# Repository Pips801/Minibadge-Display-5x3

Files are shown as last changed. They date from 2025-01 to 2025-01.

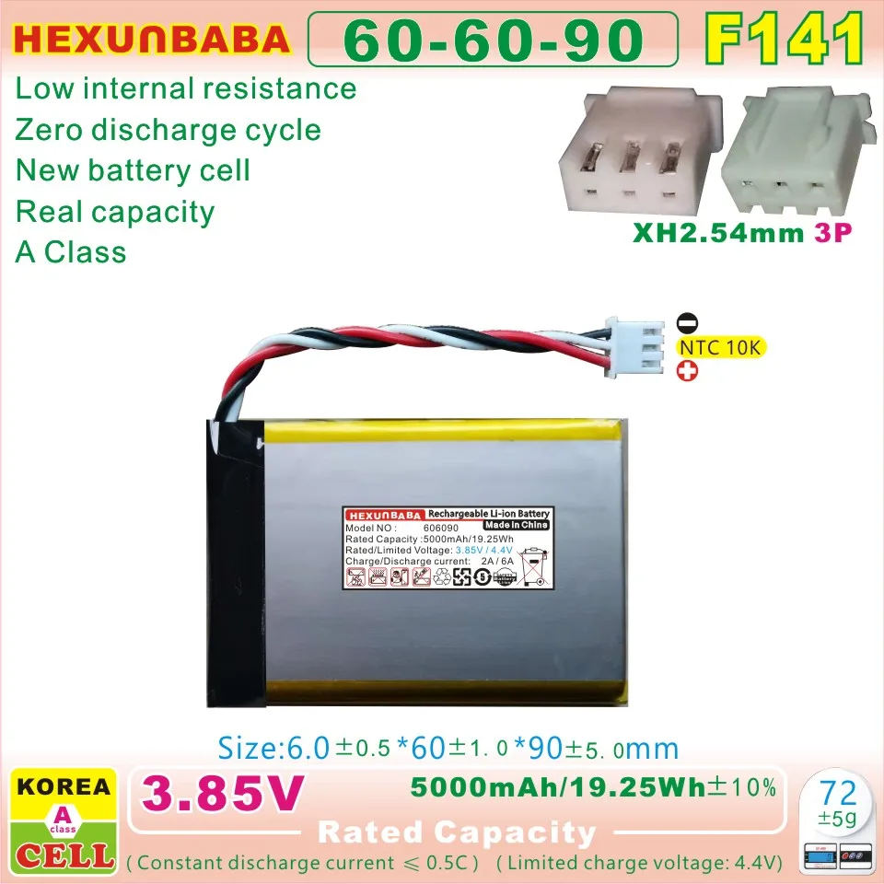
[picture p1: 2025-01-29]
Hardware/Main board/606090 F141 JST Battery.png

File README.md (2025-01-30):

# Minibadge-Display-5x3
 Battery-powered 5x3 SAINTCON Minibadge display

## Description
Battery-powered RP2040 controlled 5x3 minibadge display

MCU: RP2040

Battery: 606090 5000mAh + JST XH 3 pin 2.54mm

BMS: BQ25895

LEDs: WS2812B-2020

## Costs

| Completed? | Purchase type | Price | Cost per item |
| --- | --- | --- | --- |
| No | Parts | $161.01 | $3.22 |
| No | Main PCB | $69.00  | $1.38 |
| No | PCBA | $101.84 | $2.04 |
| No | Batteries | $215.00 | $4.30 |
| No | Front PCB | $50.01  | $1.00 |
| No | PCB Shipping | $150.00 | $3.00 |
| No | Battery Shipping | $100.00 | $2.00 |
| **Item quantity** | | **Total** | **Total cost per item** |
| 50 | | $846.86 | $16.94 |

| Completed? | Purchase type | Price | Cost per item |
| --- | --- | --- | --- |
| No | Parts | $131.22 | $5.25 |
| No | Main PCB | $28.70  | $1.15 |
| No | PCBA | $57.11  | $2.28 |
| No | Batteries | $107.50 | $4.30 |
| No | Front PCB | $37.50  | $1.50 |
| No | PCB Shipping | $80.00  | $3.20 |
| No | Battery Shipping | $53.35  | $2.13 |
| **Item quantity** | | **Total** | **Total cost per item** |
| 25 | | $495.38 | $19.82 |

## BOM

|Designator |Footprint |Quantity|Value |LCSC Part #|
|---|---|---|---|---|
|C1, C12, C13, C14, C15, C16, C17, C18, C19 |0603 |9 |4.7μF | |
|C10, C11, C20, C21, C22, C23, C24, C25, C26, C27, C28, C29, C34, C35, C36, C37, C38, C39, C40, C41|0402 |20 |0.1μF | |
|C2, C3, C6, C7, C9 |0603 |5 |10μF | |
|C31 |0402 |1 |1µF | |
|C32, C33 |0402 |2 |15pF | |
|C4 |1206 |1 |40μF |C426659 |
|C5 |0402 |1 |47nF | |
|C8 |0402 |1 |1µF |C52923 |
|D1 |D_SMB |1 |20v 5A |C14651 |
|D2, D3, D4, D5, D6, D7, D8, D9 |LED_WS2812B-2020_PLCC4_2.0x2.0mm |8 |WS2812B-2020 |C5349955 |
|J1 |PinSocket_2x05_P2.54mm_Vertical_SMD |1 |Board to Board | |
|J2 |JST_XH_S3B-XH-SM4-TB_1x03-1MP_P2.50mm_Horizontal |1 |BATT JST |C161860 |
|L1 |L_Vishay_IHLP-2525 |1 |2.2µH |C540967 |
|P1 |USB_C_Receptacle_HRO_TYPE-C-31-M-12 |1 |USB_C_Plug_USB2.0|C165948 |
|R1 |0603 |1 |5.23kΩ | |
|R10, R9 |0402 |2 |27.4Ω | |
|R11, R12, R13, R14, R15, R16 |0603 |6 |10kΩ | |
|R2 |0603 |1 |260Ω |C861779 |
|R3 |0603 |1 |30.1kΩ | |
|R4, R5 |0603 |2 |5.1k | |
|R6, R7, R8 |0603 |3 |1kΩ | |
|SW1 |SW_Push_1P1T_XKB_TS-1187A |1 |USB BOOT |C318884 |
|U1 |Texas_RTW_WQFN-24-1EP_4x4mm_P0.5mm_EP2.7x2.7mm_ThermalVias|1 |BQ25895 |C80200 |
|U10 |Crystal_SMD_Abracon_ABM8G-4Pin_3.2x2.5mm |1 |ABM8-272-T3 |C20625731  |
|U2 |SOIC-8_5.23x5.23mm_P1.27mm |1 |W25Q32JVSS |C82344 |
|U3 |QFN-10-RSE |1 |TS3USB221A |C128396 |
|U4, U5, U6, U7 |SOT-223-3_TabPin2 |4 |AP7361C-33E |C500795 |
|U8 |SOIC-8_3.9x4.9mm_P1.27mm |1 |TPM8837C |C7436831 |
|U9 |QFN-56-1EP_7x7mm_P0.4mm_EP3.2x3.2mm_ThermalVias |1 |RP2040 |C2040 |

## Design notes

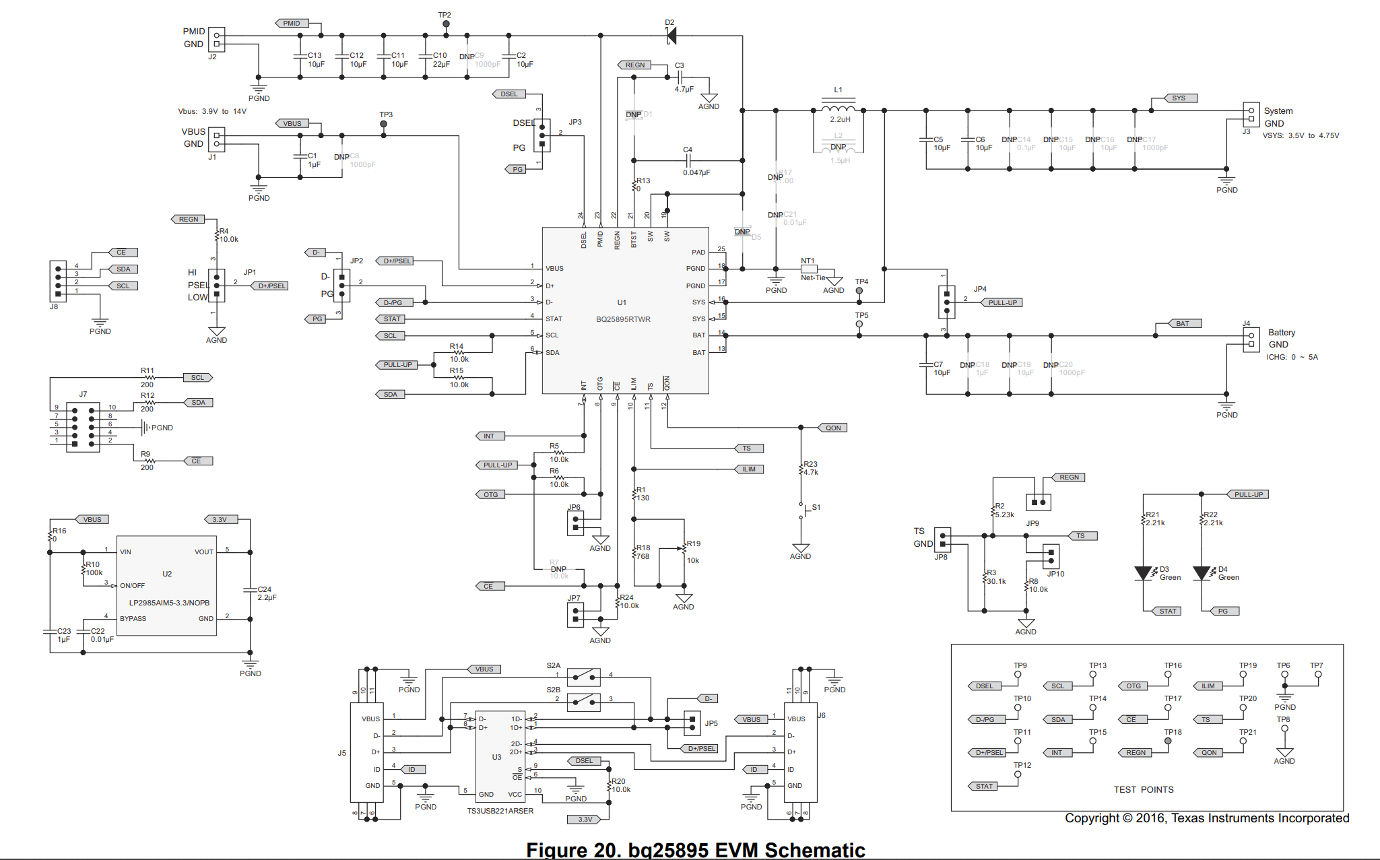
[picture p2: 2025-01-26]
Hardware/Main board/BQ25895RTW/EMV schematic.png

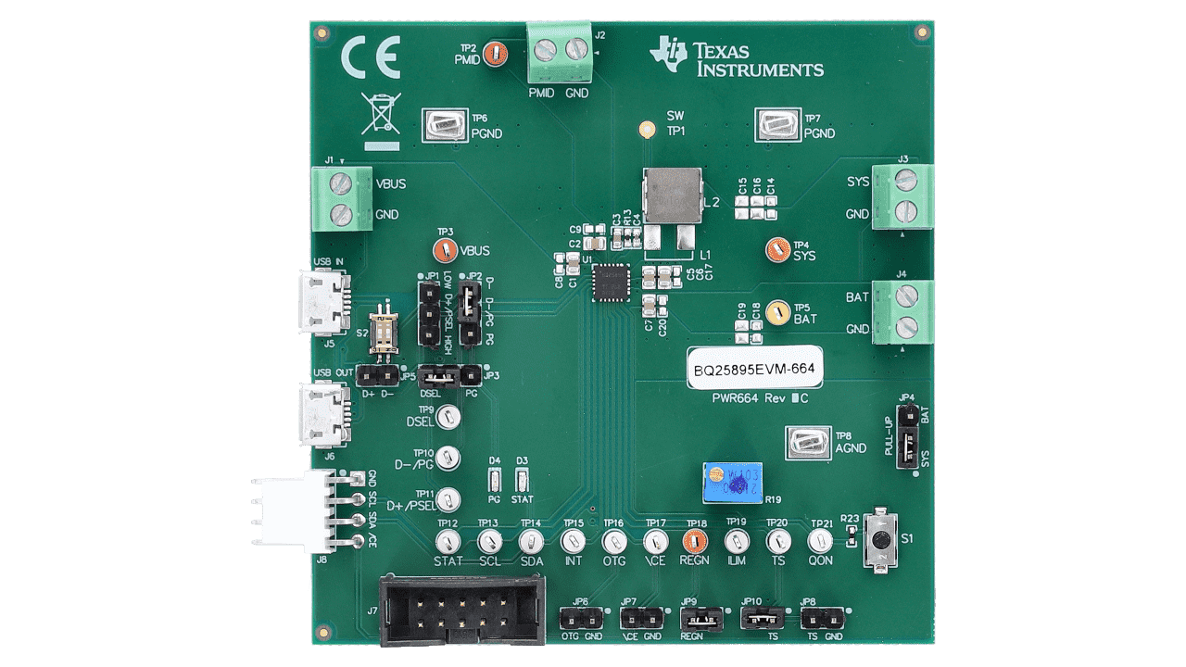
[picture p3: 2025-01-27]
Hardware/Main board/BQ25895RTW/EMV board.png

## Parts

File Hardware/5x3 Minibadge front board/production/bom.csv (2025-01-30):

Designator | Footprint | Quantity | Value | LCSC Part #
J1 | PinHeader_2x05_P2.54mm_Vertical_SMD | 1 | Board to Board
MB1, MB10, MB11, MB12, MB13, MB14, MB15, MB2, MB3, MB4, MB5, MB6, MB7, MB8, MB9 | MiniBadge_Slot_Reflective | 15 | MiniBadge_Full

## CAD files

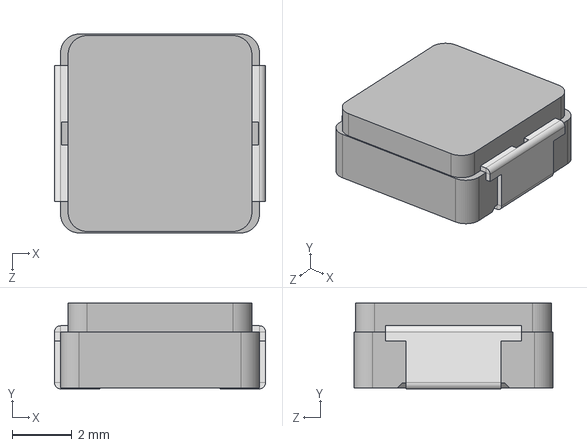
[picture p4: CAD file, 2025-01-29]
Hardware/Main board/IHLP2525/IHLP2525CZ.step
7.08 x 2.88 x 6.67 mm

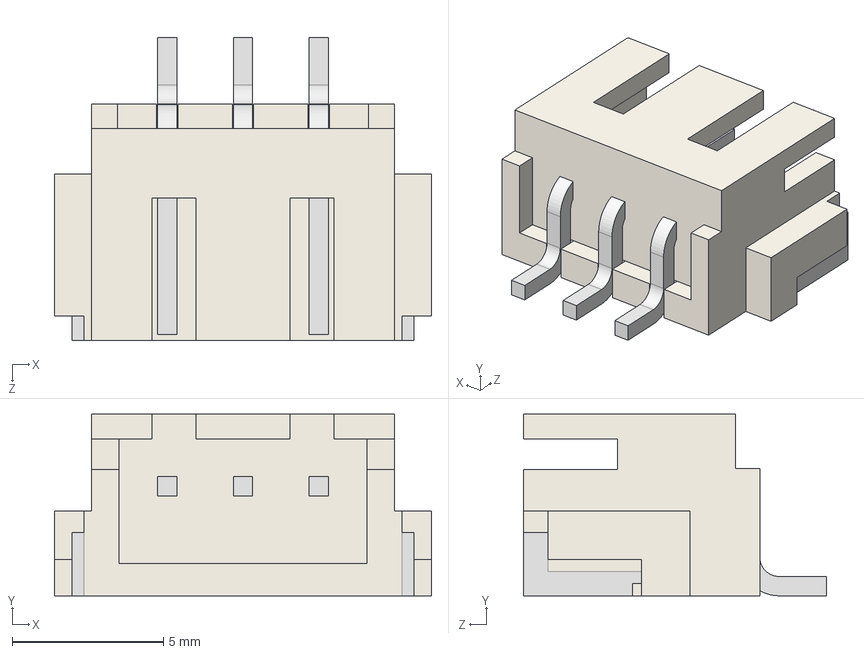
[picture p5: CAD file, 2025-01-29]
Hardware/Main board/S3B-XH-SM4-TB/S3B-XH-SM4-TB_LF__SN_.stp
12.5 x 6.00 x 10.0 mm

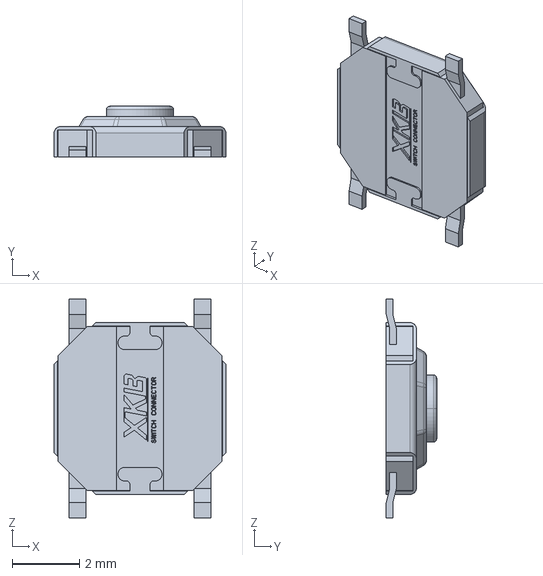
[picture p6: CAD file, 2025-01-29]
Hardware/Main board/TS-1187A/3D/TS-1187A-B-A-B.stp
5.10 x 1.50 x 6.50 mm

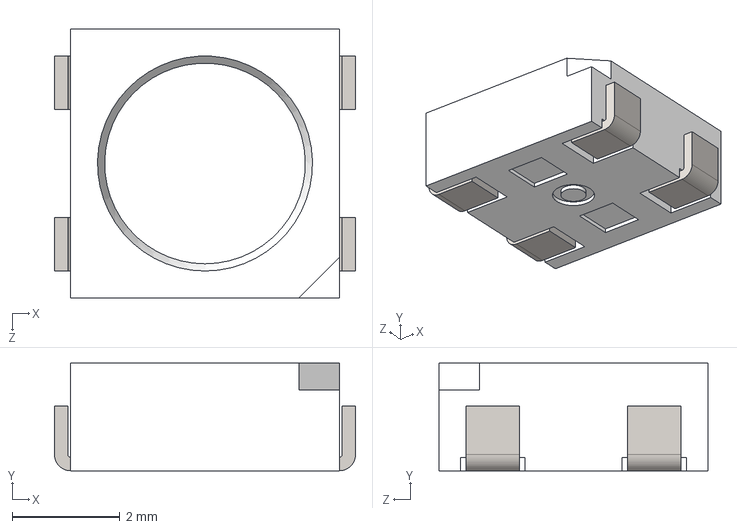
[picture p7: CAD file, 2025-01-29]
Hardware/Main board/WS2812C-2020/3D/WS2812B-V3.stp
5.60 x 2.00 x 5.00 mm

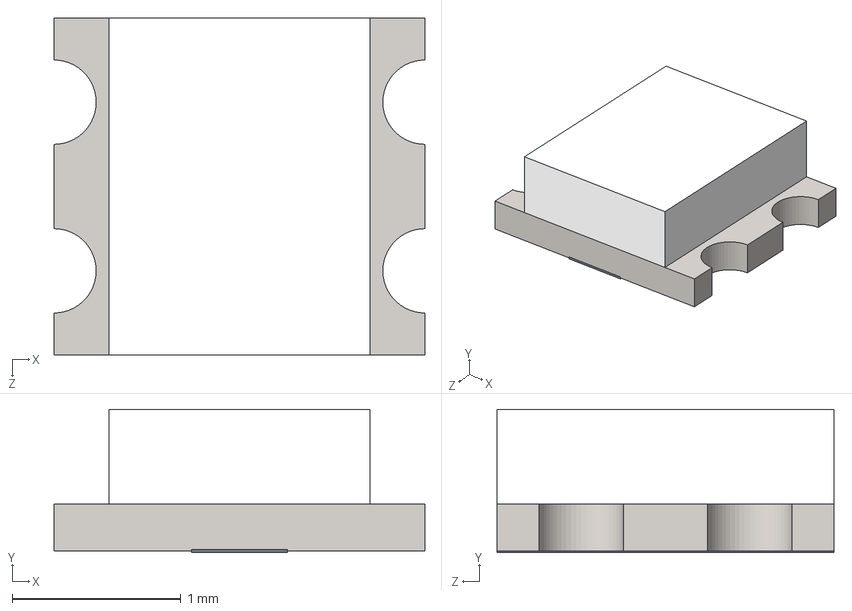
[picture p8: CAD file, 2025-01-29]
Hardware/Main board/WS2812C-2020/3D/WS2812C-2020.stp
2.20 x 0.85 x 2.00 mm

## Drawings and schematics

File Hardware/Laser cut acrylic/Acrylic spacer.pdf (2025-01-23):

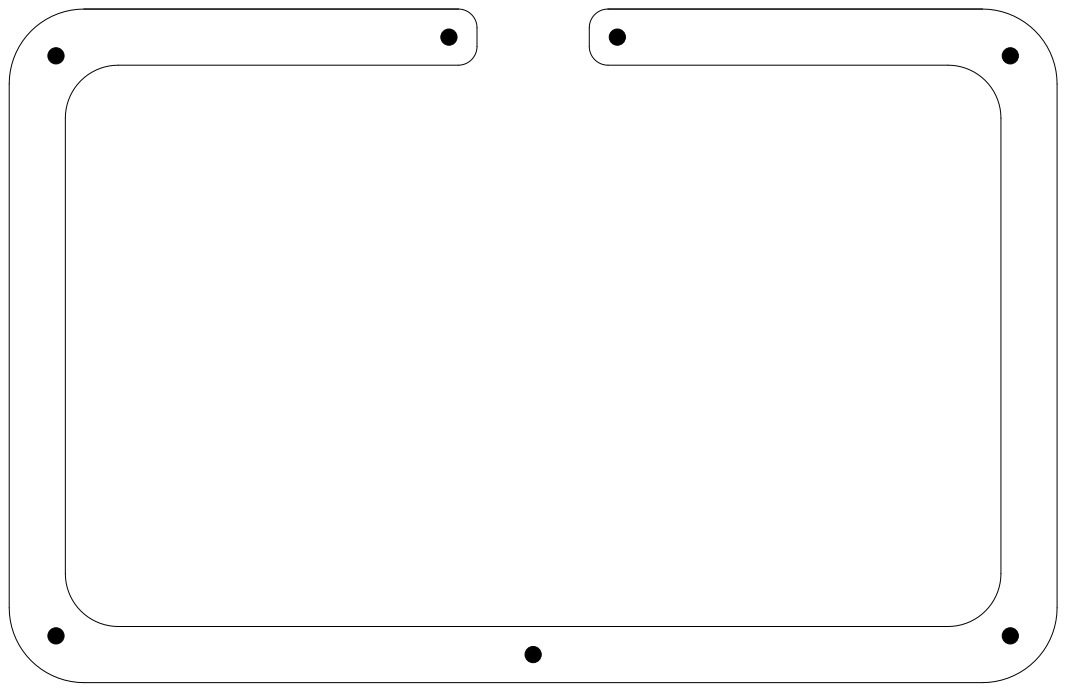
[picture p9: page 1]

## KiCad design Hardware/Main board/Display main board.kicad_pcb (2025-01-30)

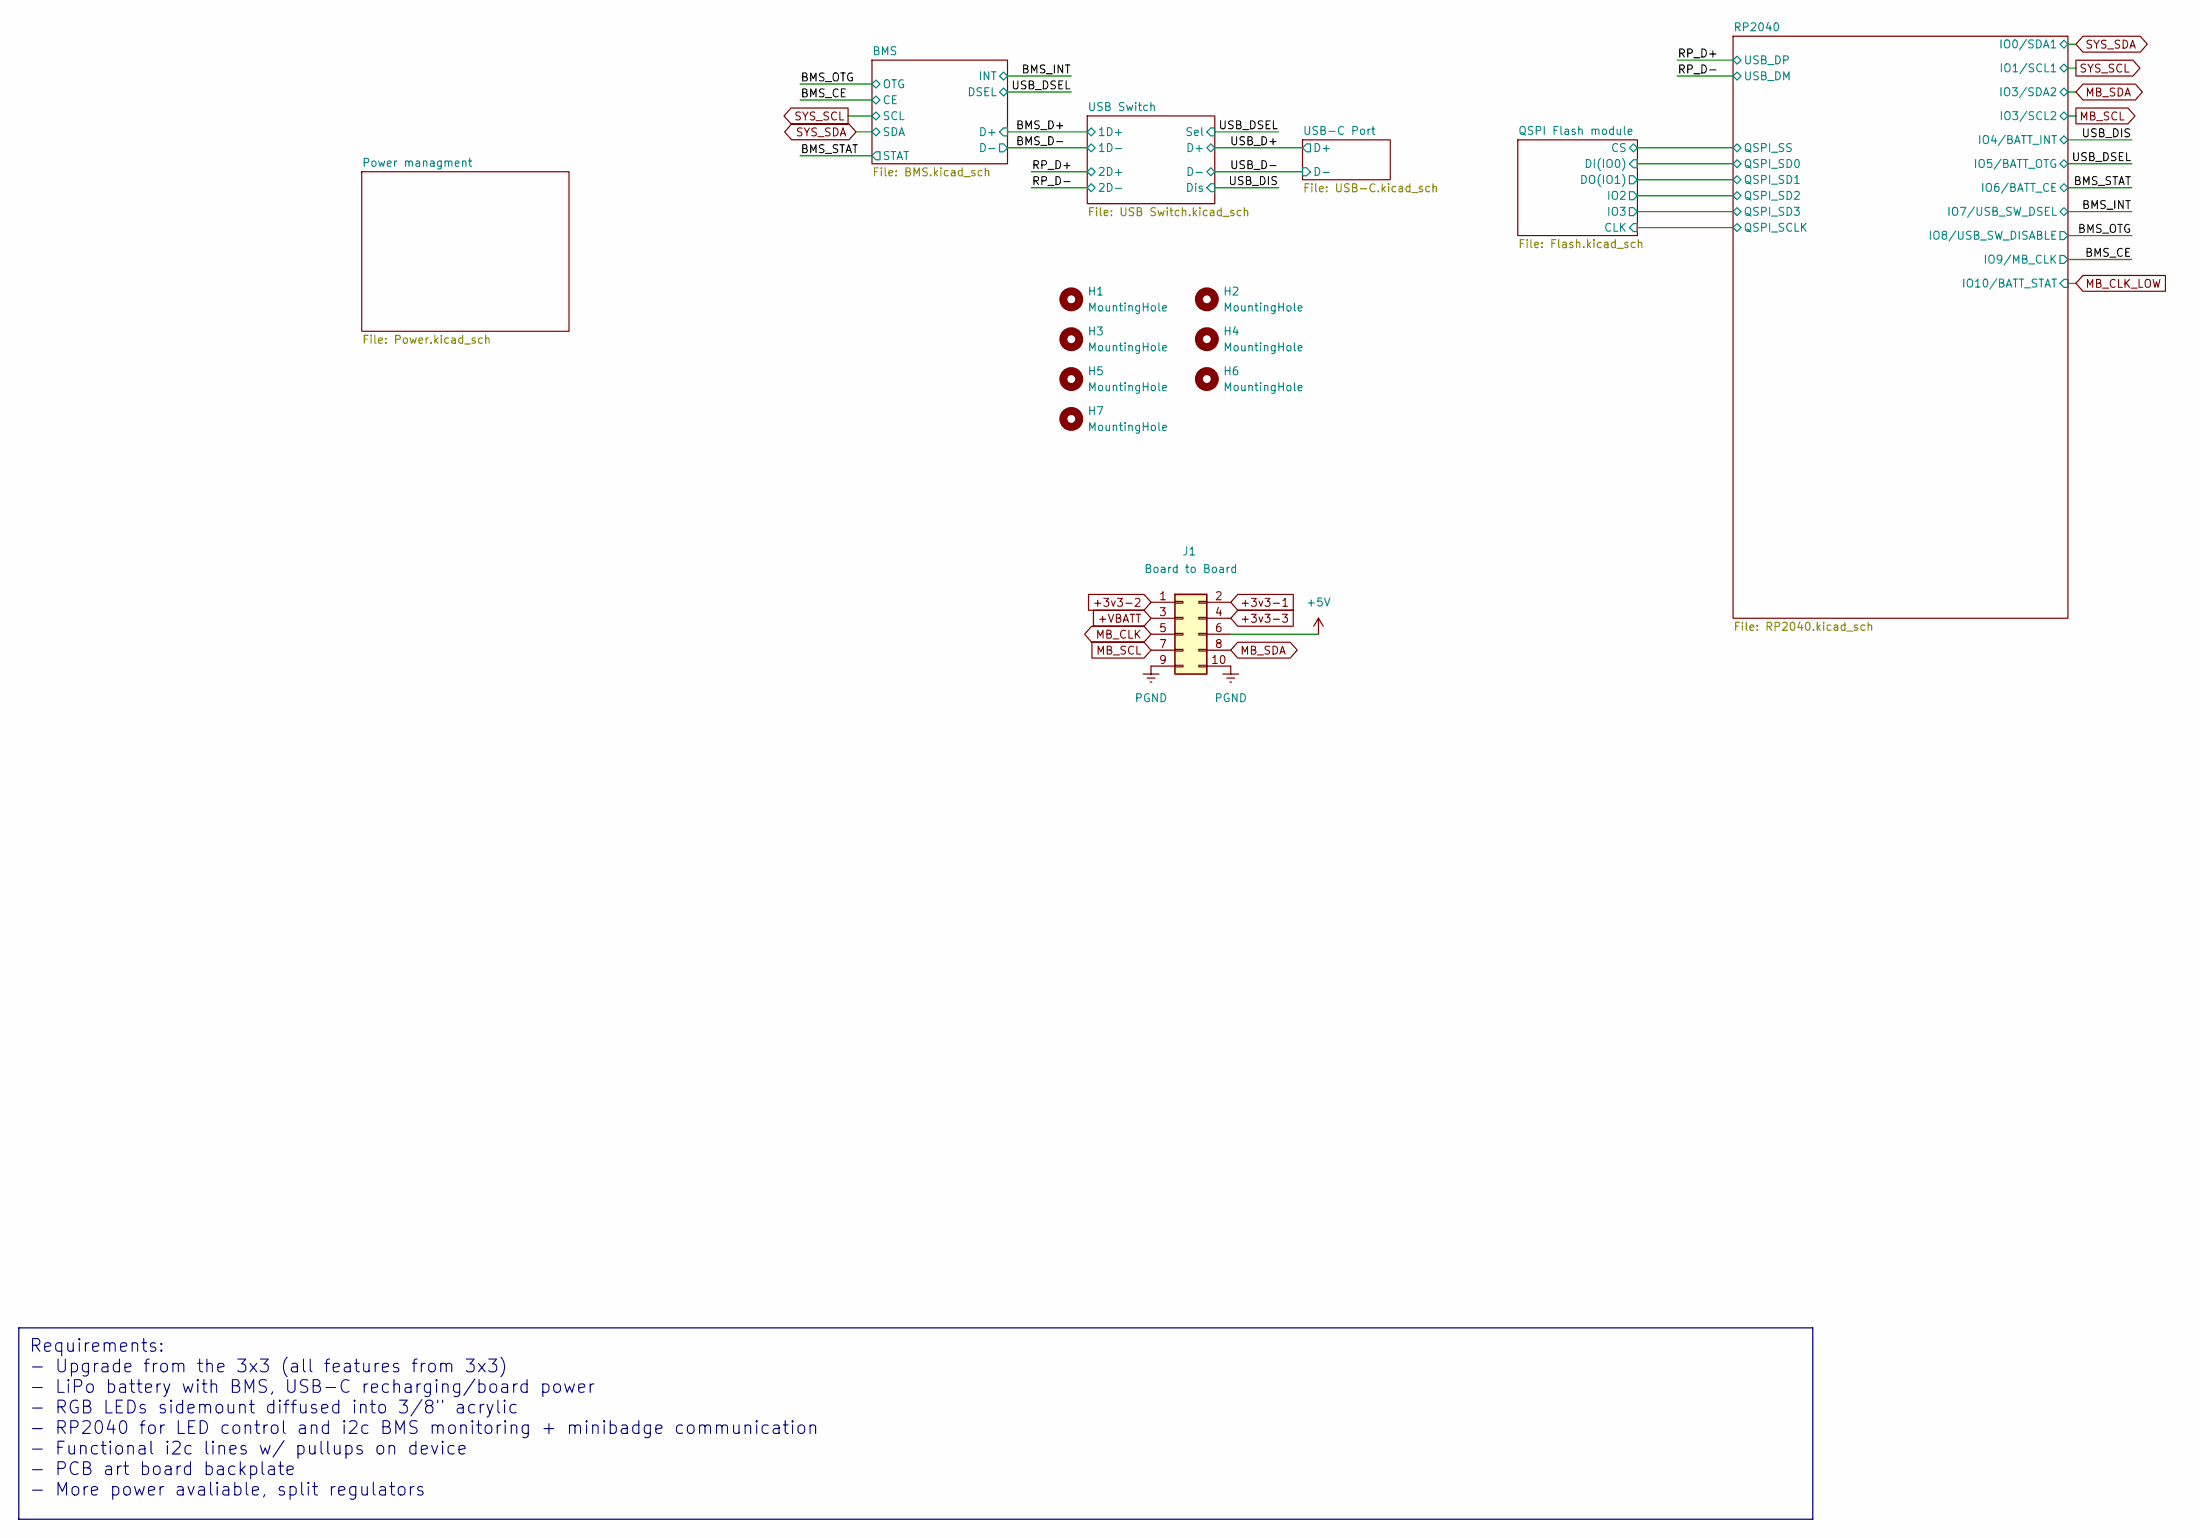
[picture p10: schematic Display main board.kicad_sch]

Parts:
H1, H2, H3, H4, H5, H6, H7: MountingHole; MountingHole_2.2mm_M2
J1: Board to Board; PinSocket_2x05_P2.54mm_Vertical_SMD

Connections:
+3v3-1: J1.2; also elsewhere on the board
+3v3-2: J1.1; also elsewhere on the board
+3v3-3: J1.4; also elsewhere on the board
+5V: J1.6; also elsewhere on the board
+VBATT: J1.3; also elsewhere on the board
MB_CLK: J1.5; also elsewhere on the board
MB_SCL: J1.7; also elsewhere on the board
MB_SDA: J1.8; also elsewhere on the board
PGND: J1.9, J1.10; also elsewhere on the board

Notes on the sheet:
Requirements: - Upgrade from the 3x3 (all features from 3x3) - LiPo battery with BMS, USB-C recharging/board power - RGB LEDs sidemount diffused into 3/8" acrylic - RP2040 for LED control and i2c BMS monitoring + minibadge communication - Functional i2c lines w/ pullups on device - PCB art board ba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

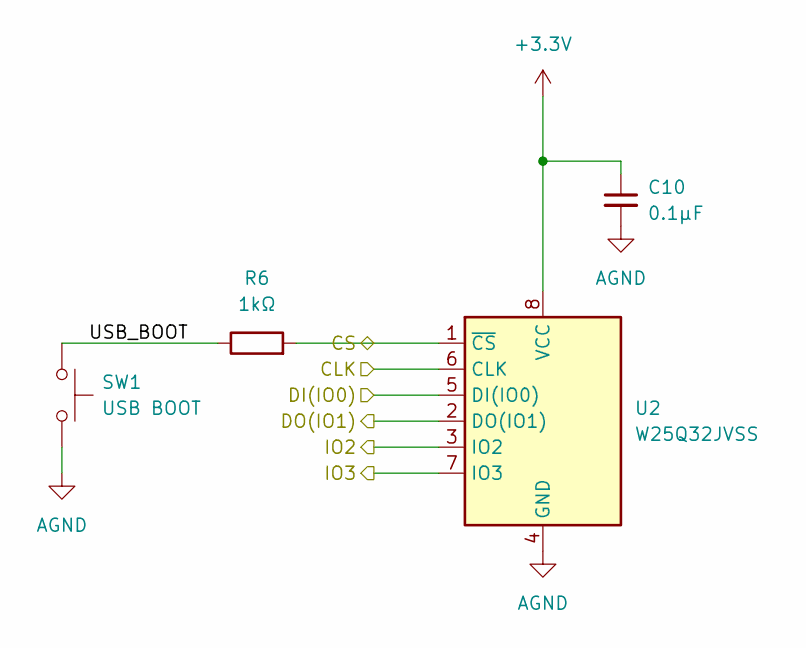
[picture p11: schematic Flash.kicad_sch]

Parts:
C10: 0.1μF; C_0402_1005Metric
R6: 1kΩ; R_0603_1608Metric
SW1: USB BOOT; SW_Push_1P1T_XKB_TS-1187A; LCSC Part # C318884
U2: W25Q32JVSS; SOIC-8_5.23x5.23mm_P1.27mm; JLCPCB Part # C82344

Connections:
+3.3V: C10.1, U2.8 (VCC); also elsewhere on the board
/QSPI Flash module/CLK: U2.6 (CLK); also elsewhere on the board
/QSPI Flash module/CS: R6.2, U2.1 (~CS); also elsewhere on the board
/QSPI Flash module/DI(IO0): U2.5 (DI(IO0)); also elsewhere on the board
/QSPI Flash module/DO(IO1): U2.2 (DO(IO1)); also elsewhere on the board
/QSPI Flash module/IO2: U2.3 (IO2); also elsewhere on the board
/QSPI Flash module/IO3: U2.7 (IO3); also elsewhere on the board
/QSPI Flash module/USB_BOOT: R6.1, SW1.1
AGND: C10.2, SW1.2, U2.4 (GND); also elsewhere on the board

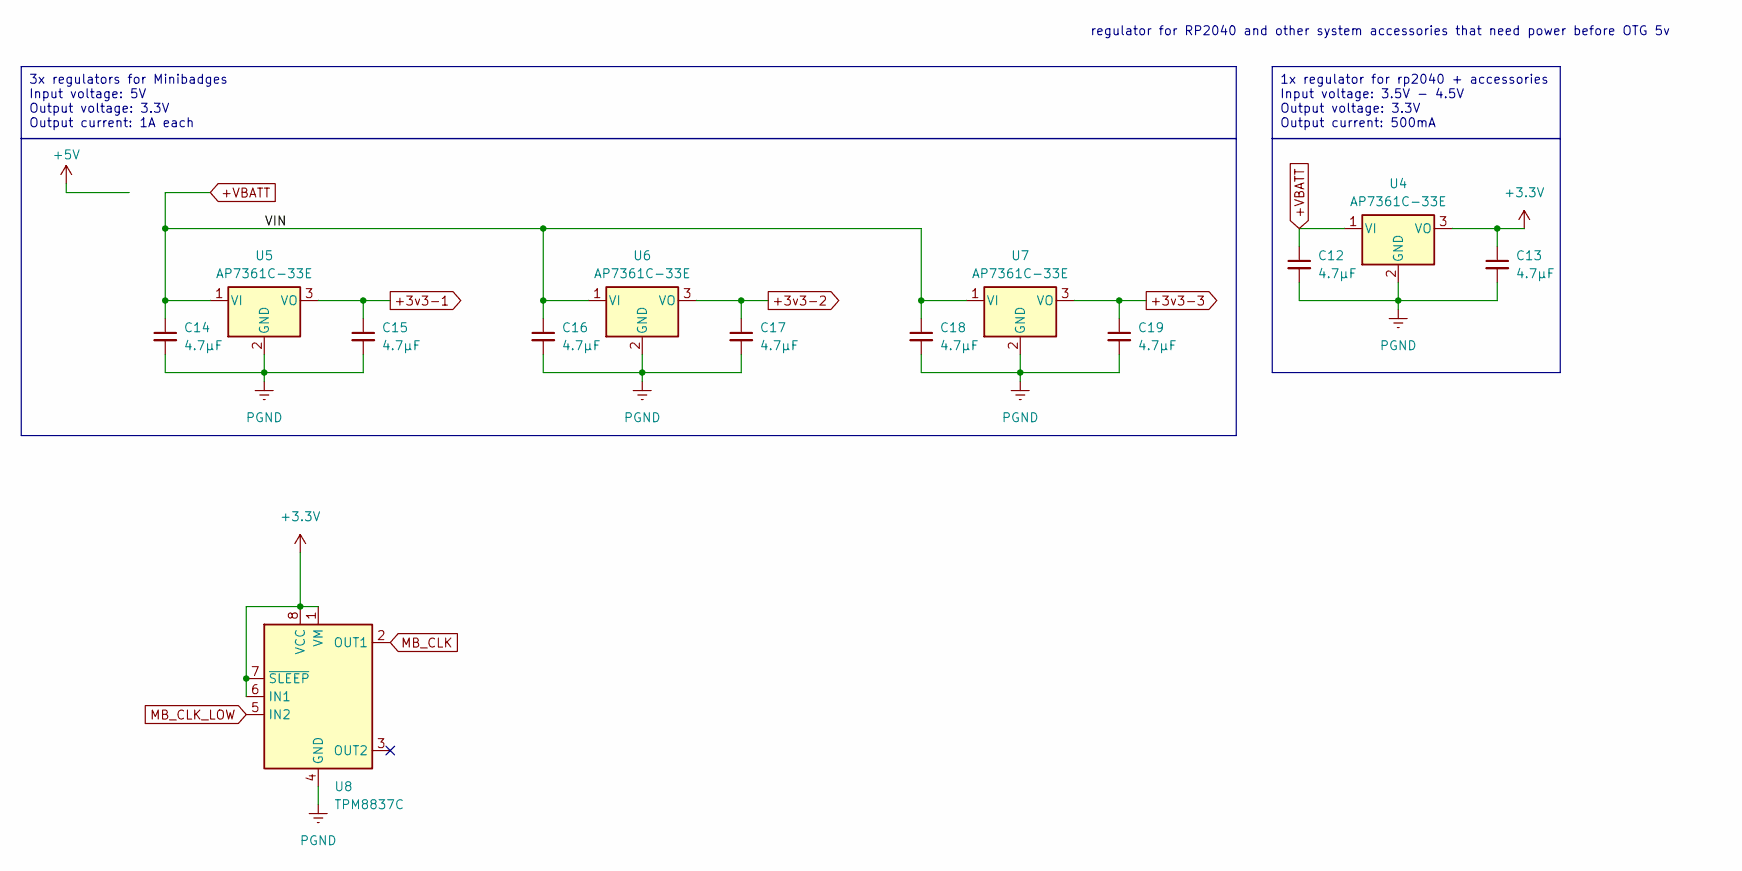
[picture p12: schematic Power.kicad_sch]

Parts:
C12, C13, C14, C15, C16, C17, C18, C19: 4.7μF; C_0603_1608Metric
U4, U5, U6, U7: AP7361C-33E; SOT-223-3_TabPin2; JLCPCB Part # C500795
U8: TPM8837C; SOIC-8_3.9x4.9mm_P1.27mm; JLCPCB Part # C7436831

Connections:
+3.3V: C13.1, U4.3 (VO), U8.1 (VM), U8.6 (IN1), U8.7 (~SLEEP), U8.8 (VCC); also elsewhere on the board
+3v3-1: C15.1, U5.3 (VO); also elsewhere on the board
+3v3-2: C17.1, U6.3 (VO); also elsewhere on the board
+3v3-3: C19.1, U7.3 (VO); also elsewhere on the board
+VBATT: C12.1, C14.1, C16.1, C18.1, U4.1 (VI), U5.1 (VI), U6.1 (VI), U7.1 (VI); also elsewhere on the board
MB_CLK: U8.2 (OUT1); also elsewhere on the board
MB_CLK_LOW: U8.5 (IN2); also elsewhere on the board
PGND: C12.2, C13.2, C14.2, C15.2, C16.2, C17.2, C18.2, C19.2, U4.2 (GND), U5.2 (GND), U6.2 (GND), U7.2 (GND), U8.4 (GND), U8.9 (GND); also elsewhere on the board

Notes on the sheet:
1x regulator for rp2040 + accessories Input voltage: 3.5V - 4.5V Output voltage: 3.3V Output current: 500mA
3x regulators for Minibadges Input voltage: 5V Output voltage: 3.3V Output current: 1A each
regulator for RP2040 and other system accessories that need power before OTG 5v

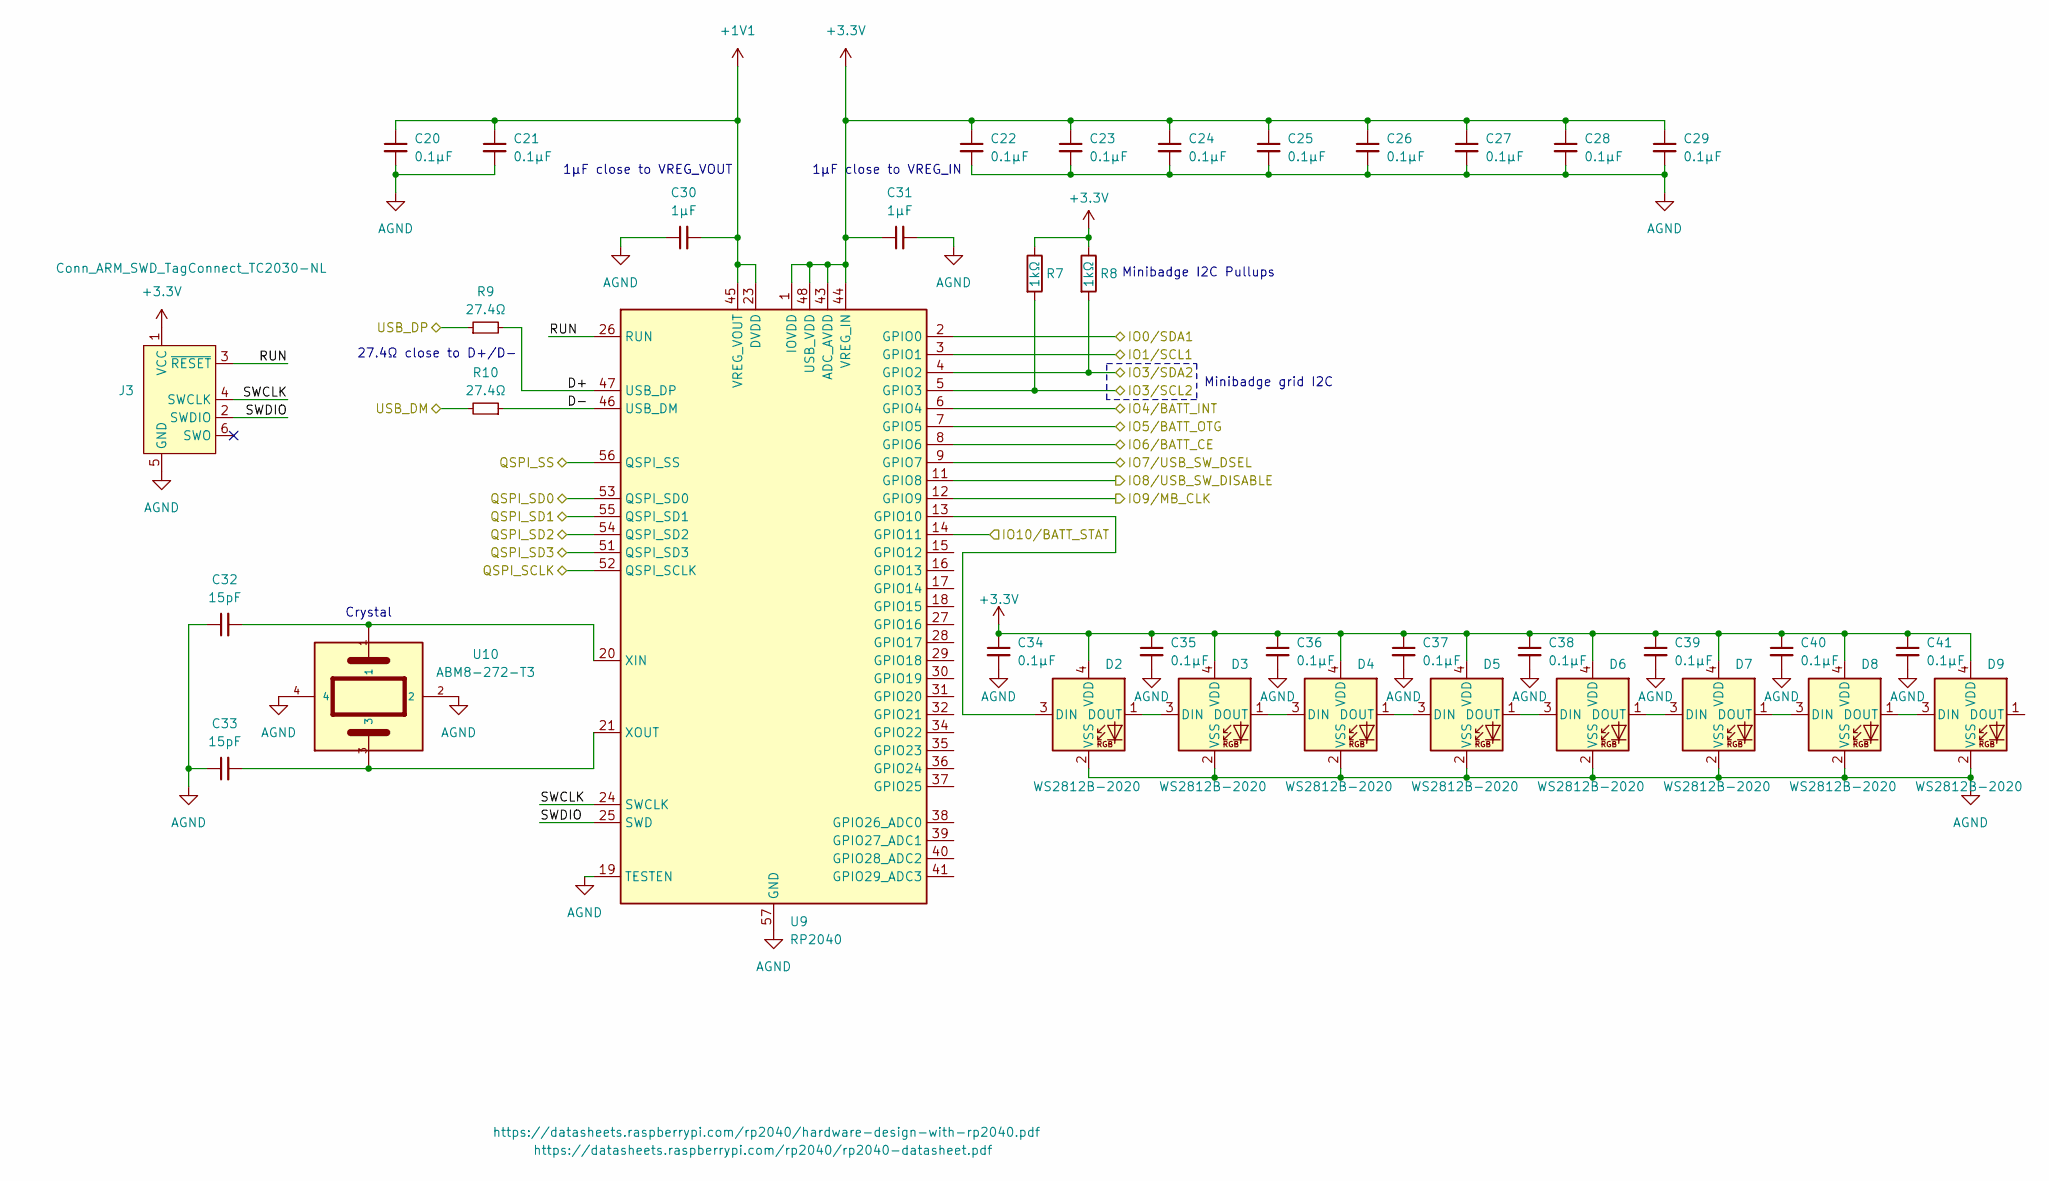
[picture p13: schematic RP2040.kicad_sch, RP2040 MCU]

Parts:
C20, C21, C22, C23, C24, C25, C26, C27, C28, C29: 0.1µF; C_0402_1005Metric
C30, C31: 1µF; C_0402_1005Metric
C32, C33: 15pF; C_0402_1005Metric
C34, C35, C36, C37, C38, C39, C40, C41: 0.1μF; C_0402_1005Metric
D2, D3, D4, D5, D6, D7, D8, D9: WS2812B-2020; LED_WS2812B-2020_PLCC4_2.0x2.0mm; JLCPCB Part # C5349955
J3: Conn_ARM_SWD_TagConnect_TC2030-NL; Paw-Connect_RevB_TC2030-IDC-NL_2x03_P1.27mm_Vertical
R7, R8: 1kΩ; R_0603_1608Metric
R9, R10: 27.4Ω; R_0402_1005Metric
U9: RP2040; QFN-56-1EP_7x7mm_P0.4mm_EP3.2x3.2mm_ThermalVias; JLCPCB Part # C2040
U10: ABM8-272-T3; Crystal_SMD_Abracon_ABM8G-4Pin_3.2x2.5mm; JLCPCB Part # C20625731

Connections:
+1V1: C20.1, C21.1, C30.2, U9.23 (DVDD), U9.45 (VREG_VOUT), U9.50 (DVDD)
+3.3V: C22.1, C23.1, C24.1, C25.1, C26.1, C27.1, C28.1, C29.1, C31.1, C34.1, C35.1, C36.1, C37.1, C38.1, C39.1, C40.1, C41.1, D2.4 (VDD), D3.4 (VDD), D4.4 (VDD), D5.4 (VDD), D6.4 (VDD), D7.4 (VDD), D8.4 (VDD), D9.4 (VDD), J3.1 (VCC), R7.1, R8.1, U9.1 (IOVDD), U9.10 (IOVDD), U9.22 (IOVDD), U9.33 (IOVDD), U9.42 (IOVDD), U9.43 (ADC_AVDD), U9.44 (VREG_IN), U9.48 (USB_VDD), U9.49 (IOVDD); also elsewhere on the board
/BMS_CE: U9.12 (GPIO9); also elsewhere on the board
/BMS_INT: U9.9 (GPIO7); also elsewhere on the board
/BMS_OTG: U9.11 (GPIO8); also elsewhere on the board
/BMS_STAT: U9.8 (GPIO6); also elsewhere on the board
/QSPI Flash module/CLK: U9.52 (QSPI_SCLK); also elsewhere on the board
/QSPI Flash module/CS: U9.56 (QSPI_SS); also elsewhere on the board
/QSPI Flash module/DI(IO0): U9.53 (QSPI_SD0); also elsewhere on the board
/QSPI Flash module/DO(IO1): U9.55 (QSPI_SD1); also elsewhere on the board
/QSPI Flash module/IO2: U9.54 (QSPI_SD2); also elsewhere on the board
/QSPI Flash module/IO3: U9.51 (QSPI_SD3); also elsewhere on the board
/RP2040/D+: R9.2, U9.47 (USB_DP)
/RP2040/D-: R10.1, U9.46 (USB_DM)
/RP2040/RUN: J3.3 (~RESET), U9.26 (RUN)
/RP2040/SWCLK: J3.4 (SWCLK), U9.24 (SWCLK)
/RP2040/SWDIO: J3.2 (SWDIO), U9.25 (SWD)
/RP_D+: R9.1; also elsewhere on the board
/RP_D-: R10.2; also elsewhere on the board
/USB_DIS: U9.6 (GPIO4); also elsewhere on the board
/USB_DSEL: U9.7 (GPIO5); also elsewhere on the board
AGND: C20.2, C21.2, C22.2, C23.2, C24.2, C25.2, C26.2, C27.2, C28.2, C29.2, C30.1, C31.2, C32.1, C33.1, C34.2, C35.2, C36.2, C37.2, C38.2, C39.2, C40.2, C41.2, D2.2 (VSS), D3.2 (VSS), D4.2 (VSS), D5.2 (VSS), D6.2 (VSS), D7.2 (VSS), D8.2 (VSS), D9.2 (VSS), J3.5 (GND), U9.19 (TESTEN), U9.57 (GND), U10.2, U10.4; also elsewhere on the board
MB_CLK_LOW: U9.14 (GPIO11); also elsewhere on the board
MB_SCL: R7.2, U9.5 (GPIO3); also elsewhere on the board
MB_SDA: R8.2, U9.4 (GPIO2); also elsewhere on the board
unnamed: D2.3 (DIN), U9.13 (GPIO10)
unnamed: D2.1 (DOUT), D3.3 (DIN)
unnamed: D3.1 (DOUT), D4.3 (DIN)
unnamed: D4.1 (DOUT), D5.3 (DIN)
unnamed: D5.1 (DOUT), D6.3 (DIN)
unnamed: D6.1 (DOUT), D7.3 (DIN)
unnamed: D7.1 (DOUT), D8.3 (DIN)
unnamed: D8.1 (DOUT), D9.3 (DIN)
unnamed: C32.2, U9.20 (XIN), U10.1
unnamed: C33.2, U9.21 (XOUT), U10.3
SYS_SCL: U9.3 (GPIO1); also elsewhere on the board
SYS_SDA: U9.2 (GPIO0); also elsewhere on the board

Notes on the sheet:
1µF close to VREG_VOUT
27.4Ω close to D+/D-
Minibadge grid I2C
Crystal
Minibadge I2C Pullups
1µF close to VREG_IN

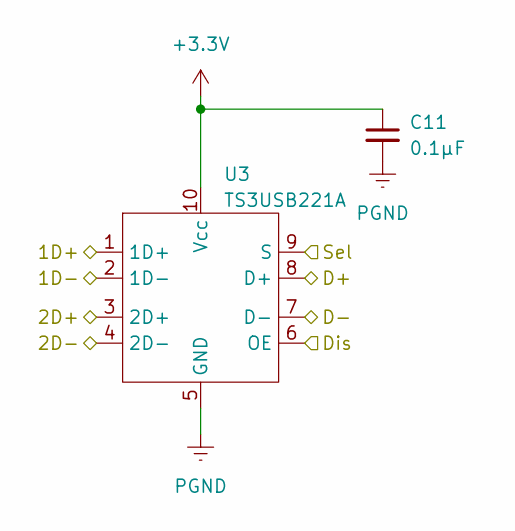
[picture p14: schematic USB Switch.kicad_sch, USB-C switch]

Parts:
C11: 0.1μF; C_0402_1005Metric
U3: TS3USB221A; QFN-10-RSE; JLCPCB Part # C128396

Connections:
+3.3V: C11.1, U3.10 (Vcc); also elsewhere on the board
/BMS_D+: U3.1 (1D+); also elsewhere on the board
/BMS_D-: U3.2 (1D-); also elsewhere on the board
/RP_D+: U3.3 (2D+); also elsewhere on the board
/RP_D-: U3.4 (2D-); also elsewhere on the board
/USB_D+: U3.8 (D+); also elsewhere on the board
/USB_D-: U3.7 (D-); also elsewhere on the board
/USB_DIS: U3.6 (OE); also elsewhere on the board
/USB_DSEL: U3.9 (S); also elsewhere on the board
PGND: C11.2, U3.5 (GND); also elsewhere on the board

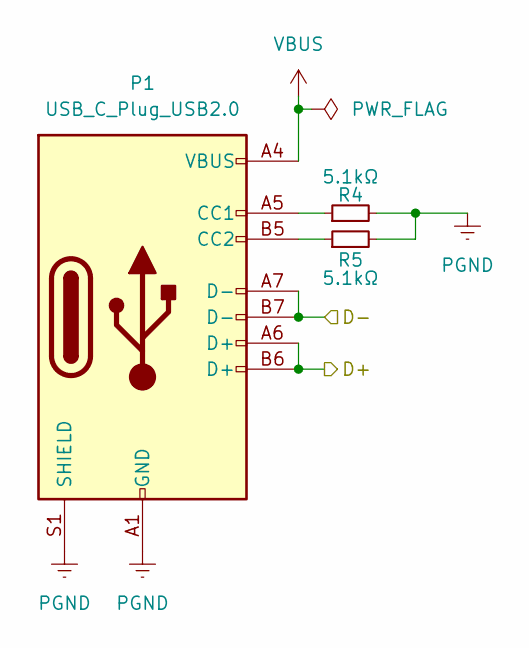
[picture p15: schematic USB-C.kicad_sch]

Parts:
P1: USB_C_Plug_USB2.0; USB_C_Receptacle_HRO_TYPE-C-31-M-12; JLCPCB Part # C165948
R4, R5: 5.1kΩ; R_0603_1608Metric

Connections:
/USB_D+: P1.A6 (D+), P1.B6 (D+); also elsewhere on the board
/USB_D-: P1.A7 (D-), P1.B7 (D-); also elsewhere on the board
unnamed: P1.A5 (CC1), R4.1
unnamed: P1.B5 (CC2), R5.1
PGND: P1.A1 (GND), P1.A12 (GND), P1.B1 (GND), P1.B12 (GND), P1.S1 (SHIELD), R4.2, R5.2; also elsewhere on the board
VBUS: P1.A4 (VBUS), P1.A9 (VBUS), P1.B4 (VBUS), P1.B9 (VBUS); also elsewhere on the board

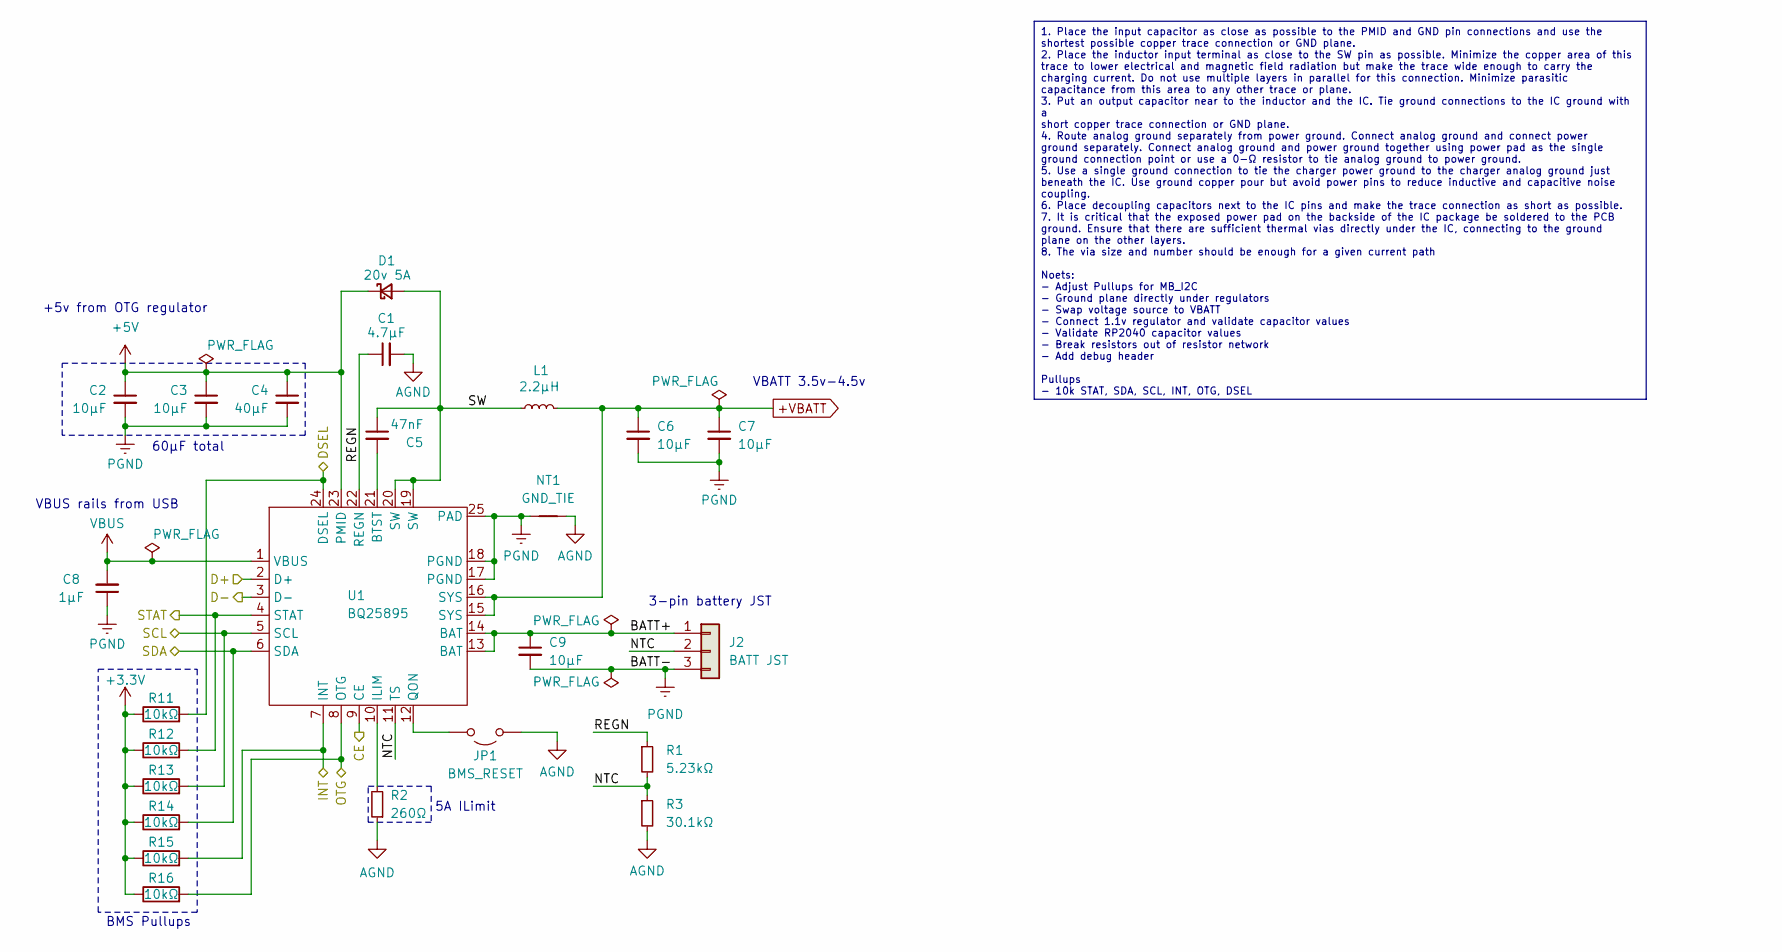
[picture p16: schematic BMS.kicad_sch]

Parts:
C1: 4.7μF; C_0603_1608Metric
C2, C3: 10μF; C_0603_1608Metric
C4: 40μF; C_1206_3216Metric; LCSC Part # C426659
C5: 47nF; C_0402_1005Metric
C6, C7, C9: 10µF; C_0603_1608Metric
C8: 1µF; C_0402_1005Metric; LCSC Part # C52923
D1: 20v 5A; D_SMB; LCSC Part # C14651
J2: BATT JST; JST_XH_S3B-XH-SM4-TB_1x03-1MP_P2.50mm_Horizontal; JLCPCB Part # C161860
JP1: BMS_RESET; SolderJumper-2_P1.3mm_Open_RoundedPad1.0x1.5mm
L1: 2.2µH; L_Vishay_IHLP-2525; LCSC Part # C540967
NT1: GND_TIE; NetTie-2_SMD_Pad0.5mm
R1: 5.23kΩ; R_0603_1608Metric
R2: 260Ω; R_0603_1608Metric; LCSC Part # C861779
R3: 30.1kΩ; R_0603_1608Metric
R11, R12, R13, R14, R15, R16: 10kΩ; R_0603_1608Metric
U1: BQ25895; Texas_RTW_WQFN-24-1EP_4x4mm_P0.5mm_EP2.7x2.7mm_ThermalVias; LCSC Part # C80200

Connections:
+3.3V: R11.1, R12.1, R13.1, R14.1, R15.1, R16.1; also elsewhere on the board
+5V: C2.1, C3.1, C4.1, D1.1 (K), U1.23 (PMID); also elsewhere on the board
+VBATT: C6.1, C7.1, L1.1, U1.15 (SYS), U1.16 (SYS); also elsewhere on the board
/BMS/BATT+: C9.1, J2.1, U1.13 (BAT), U1.14 (BAT)
/BMS/NTC: J2.2, R1.2, R3.1, U1.11 (TS)
/BMS/REGN: C1.1, R1.1, U1.22 (REGN)
/BMS/SW: C5.1, D1.2 (A), L1.2, U1.19 (SW), U1.20 (SW)
/BMS_CE: U1.9 (CE); also elsewhere on the board
/BMS_D+: U1.2 (D+); also elsewhere on the board
/BMS_D-: U1.3 (D-); also elsewhere on the board
/BMS_INT: R15.2, U1.7 (INT); also elsewhere on the board
/BMS_OTG: R16.2, U1.8 (OTG); also elsewhere on the board
/BMS_STAT: R12.2, U1.4 (STAT); also elsewhere on the board
/USB_DSEL: R11.2, U1.24 (DSEL); also elsewhere on the board
AGND: C1.2, JP1.1 (A), NT1.1, R2.1, R3.2; also elsewhere on the board
unnamed: JP1.2 (B), U1.12 (QON)
unnamed: C5.2, U1.21 (BTST)
unnamed: R2.2, U1.10 (ILIM)
PGND: C2.2, C3.2, C4.2, C6.2, C7.2, C8.1, C9.2, J2.3, NT1.2, U1.17 (PGND), U1.18 (PGND), U1.25 (PAD); also elsewhere on the board
SYS_SCL: R13.2, U1.5 (SCL); also elsewhere on the board
SYS_SDA: R14.2, U1.6 (SDA); also elsewhere on the board
VBUS: C8.2, U1.1 (VBUS); also elsewhere on the board

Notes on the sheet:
1. Place the input capacitor as close as possible to the PMID and GND pin connections and use the shortest possible copper trace connection or GND plane. 2. Place the inductor input terminal as close to the SW pin as possible. Minimize the copper area of this trace to lower electrical and magnetic 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
BMS Pullups
3-pin battery JST
VBUS rails from USB
5A ILimit
60μF total
+5v from OTG regulator
VBATT 3.5v-4.5v

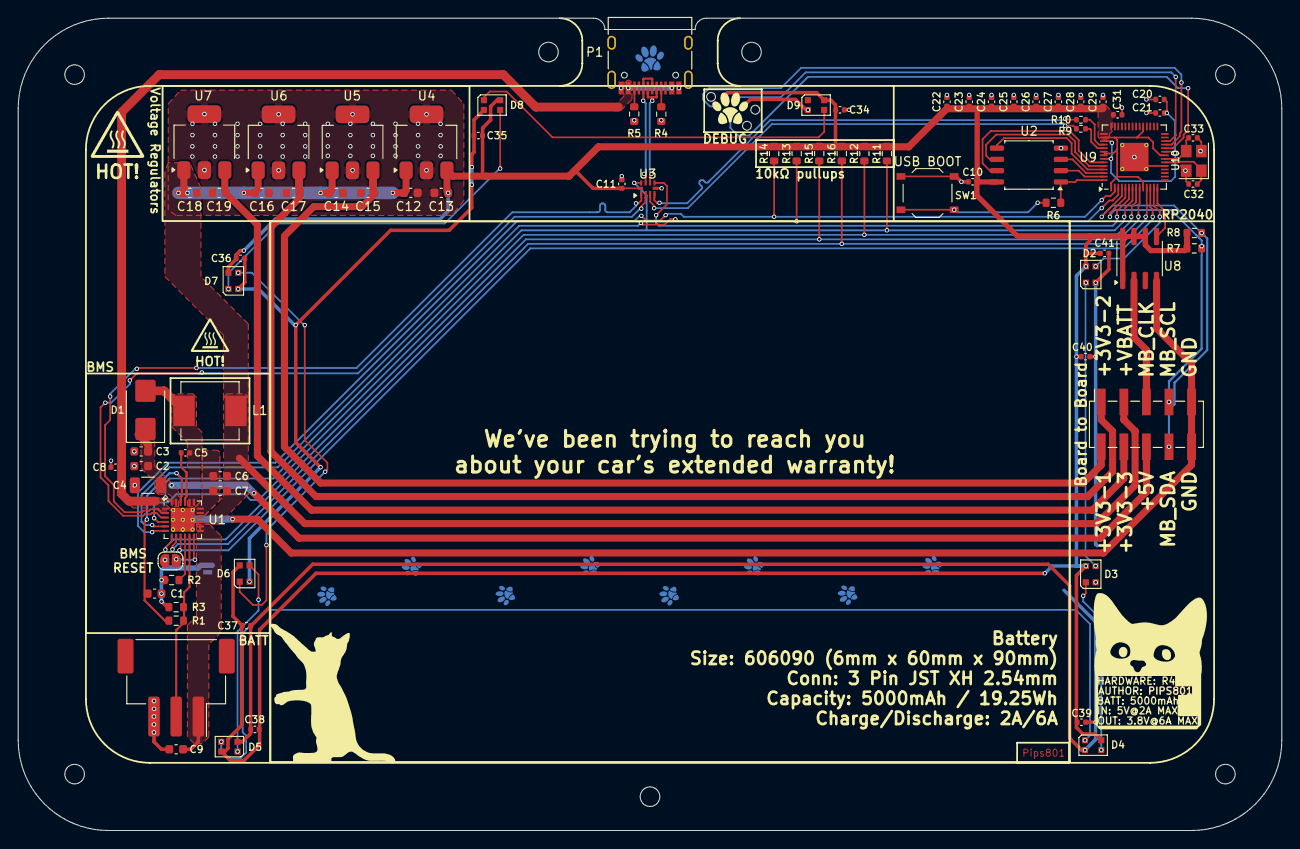
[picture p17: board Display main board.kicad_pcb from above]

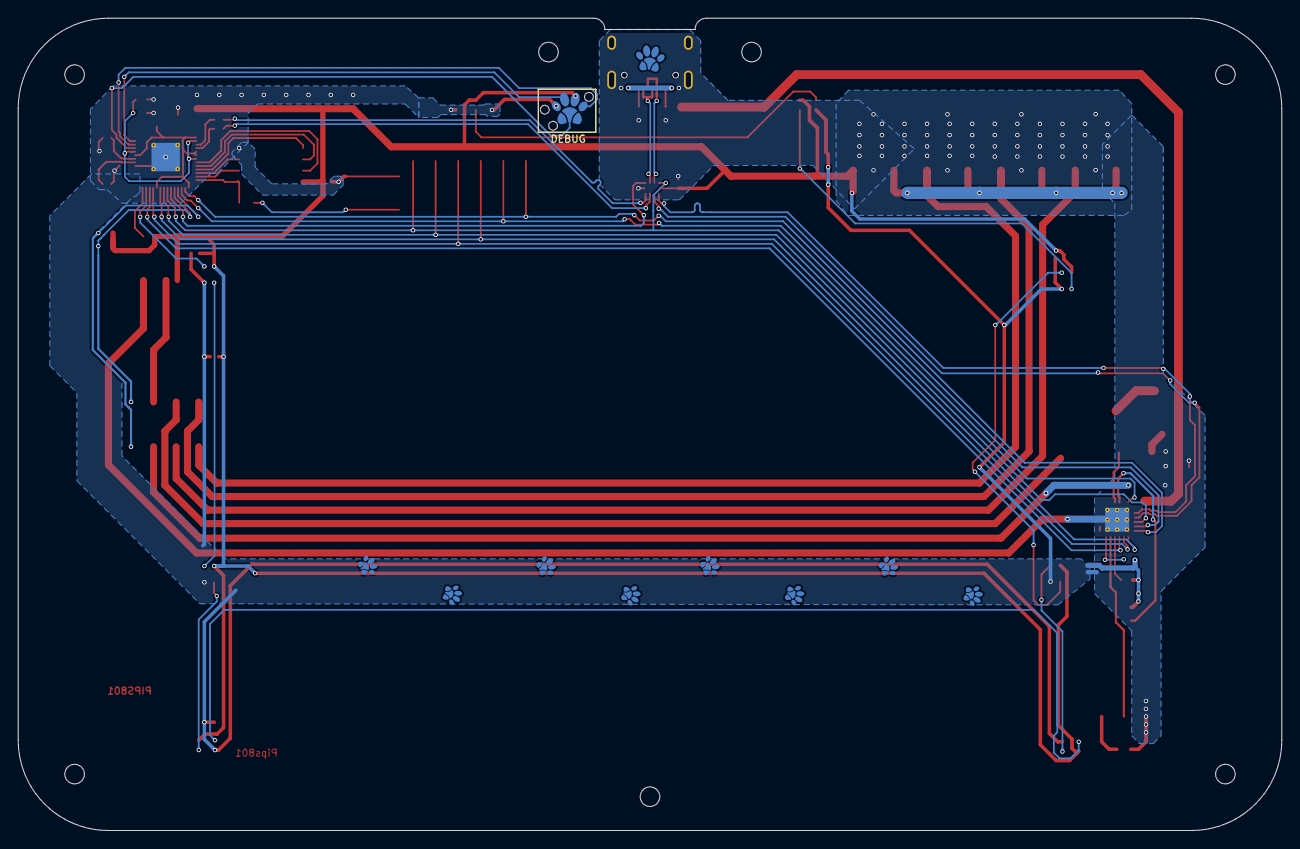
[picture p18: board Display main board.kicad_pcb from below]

Board: 2 copper layers, 142.2 x 91.4 mm, 100 parts (11 on the bottom side), 59 nets.

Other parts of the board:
G**: Paw-Connect_Silk_RevB
G**#2, G**#3, G**#4, G**#5, G**#6, G**#7, G**#8, G**#9, G**#10: Paw-Connect_Silk_RevB

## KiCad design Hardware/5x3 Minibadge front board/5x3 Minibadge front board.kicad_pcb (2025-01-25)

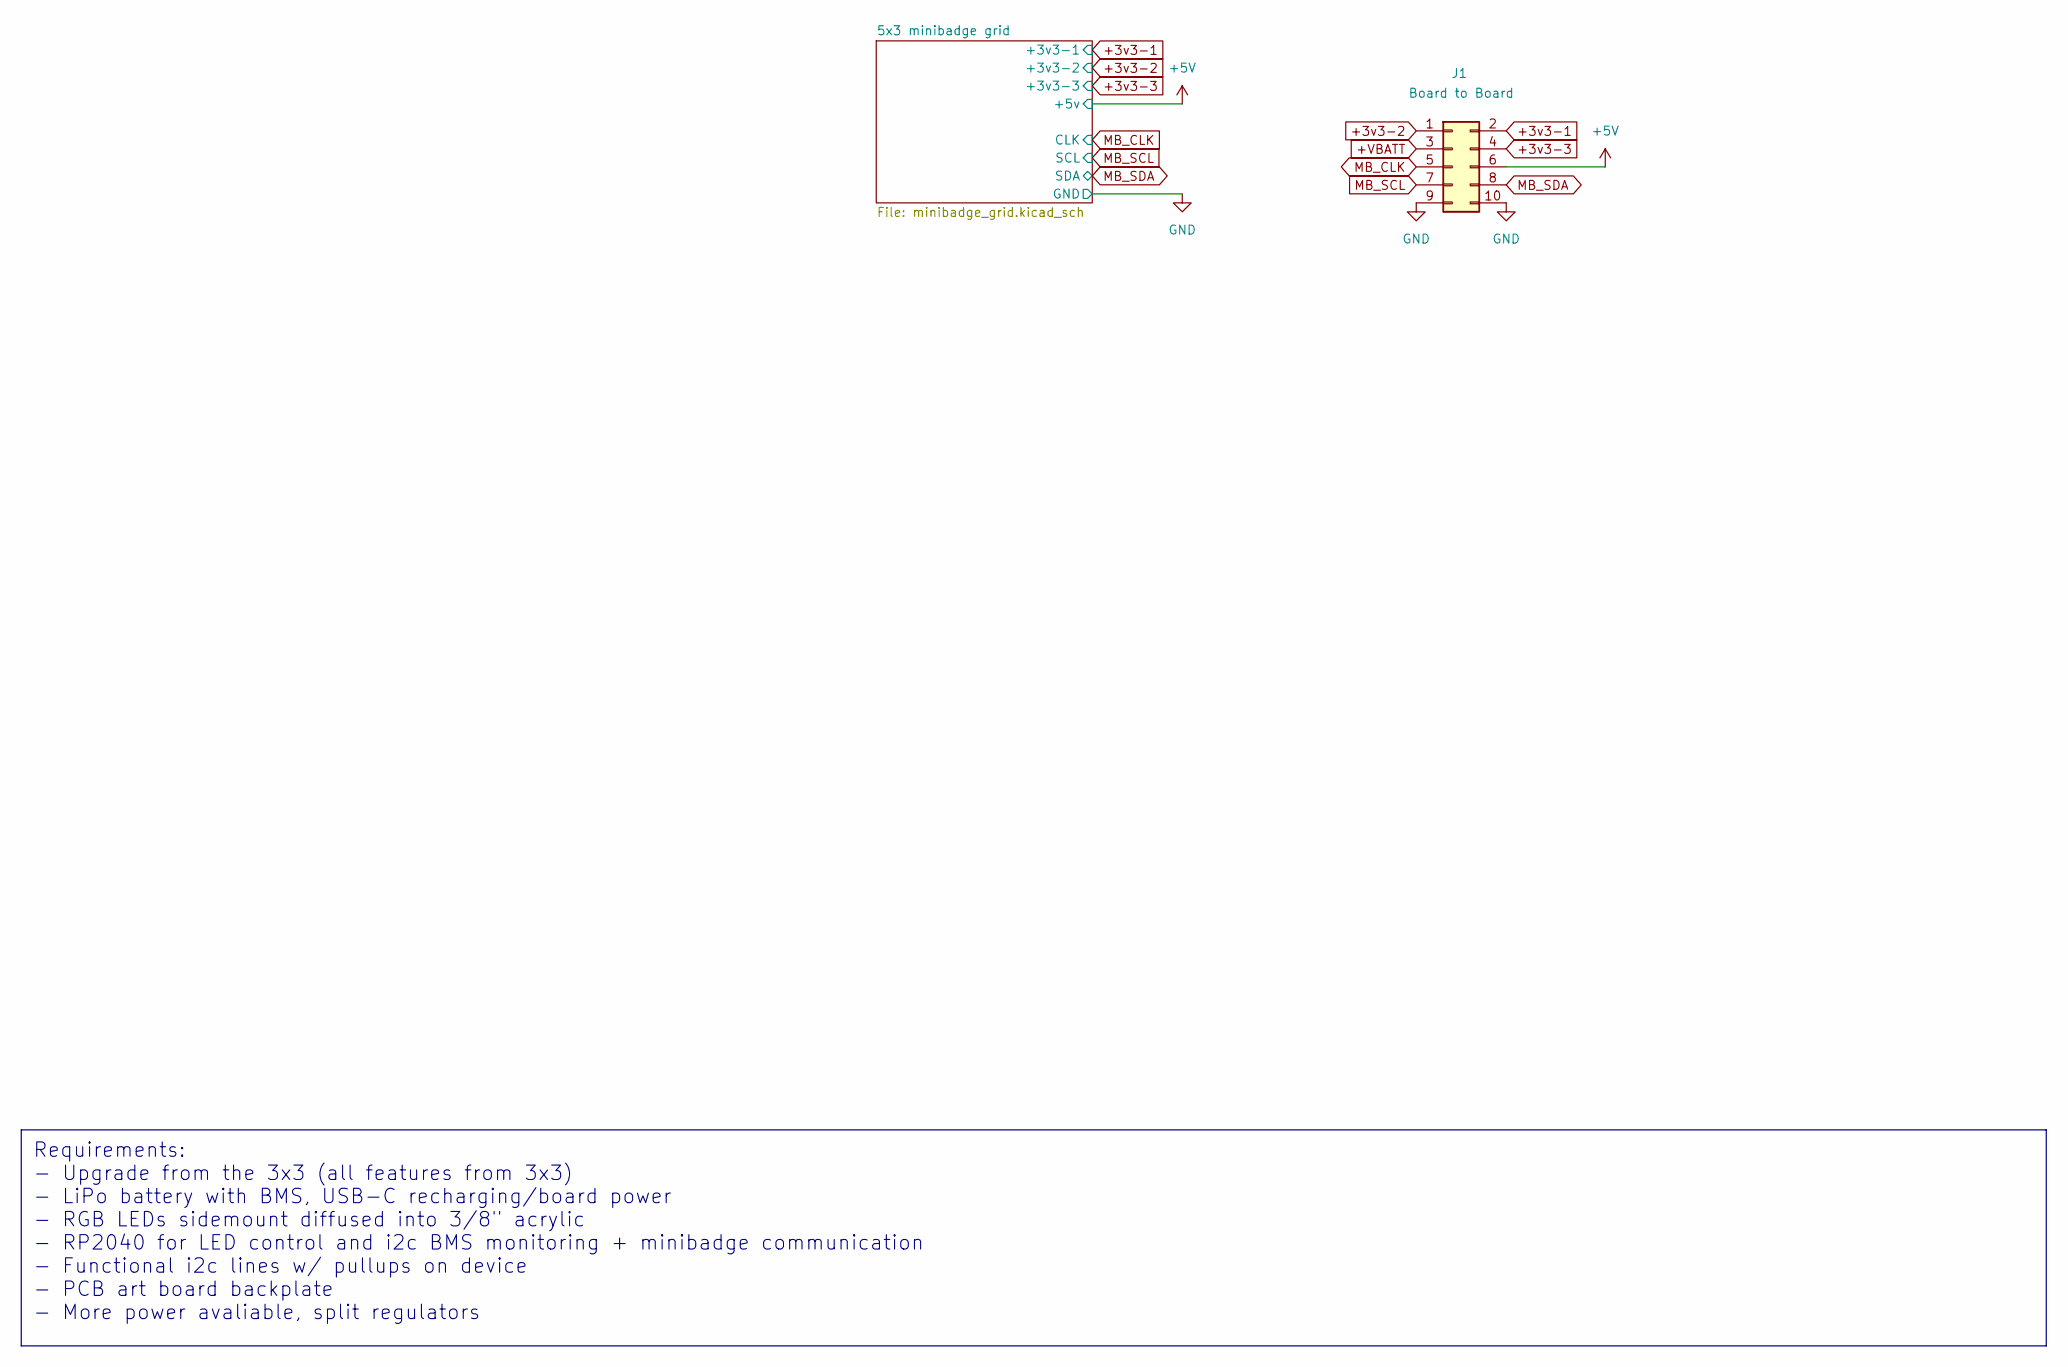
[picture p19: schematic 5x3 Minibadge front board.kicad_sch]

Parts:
J1: Board to Board; PinHeader_2x05_P2.54mm_Vertical_SMD

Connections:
+3v3-1: J1.2; also elsewhere on the board
+3v3-2: J1.1; also elsewhere on the board
+3v3-3: J1.4; also elsewhere on the board
+5V: J1.6; also elsewhere on the board
+VBATT: J1.3
GND: J1.9, J1.10; also elsewhere on the board
MB_CLK: J1.5; also elsewhere on the board
MB_SCL: J1.7; also elsewhere on the board
MB_SDA: J1.8; also elsewhere on the board

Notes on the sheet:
Requirements: - Upgrade from the 3x3 (all features from 3x3) - LiPo battery with BMS, USB-C recharging/board power - RGB LEDs sidemount diffused into 3/8" acrylic - RP2040 for LED control and i2c BMS monitoring + minibadge communication - Functional i2c lines w/ pullups on device - PCB art board ba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

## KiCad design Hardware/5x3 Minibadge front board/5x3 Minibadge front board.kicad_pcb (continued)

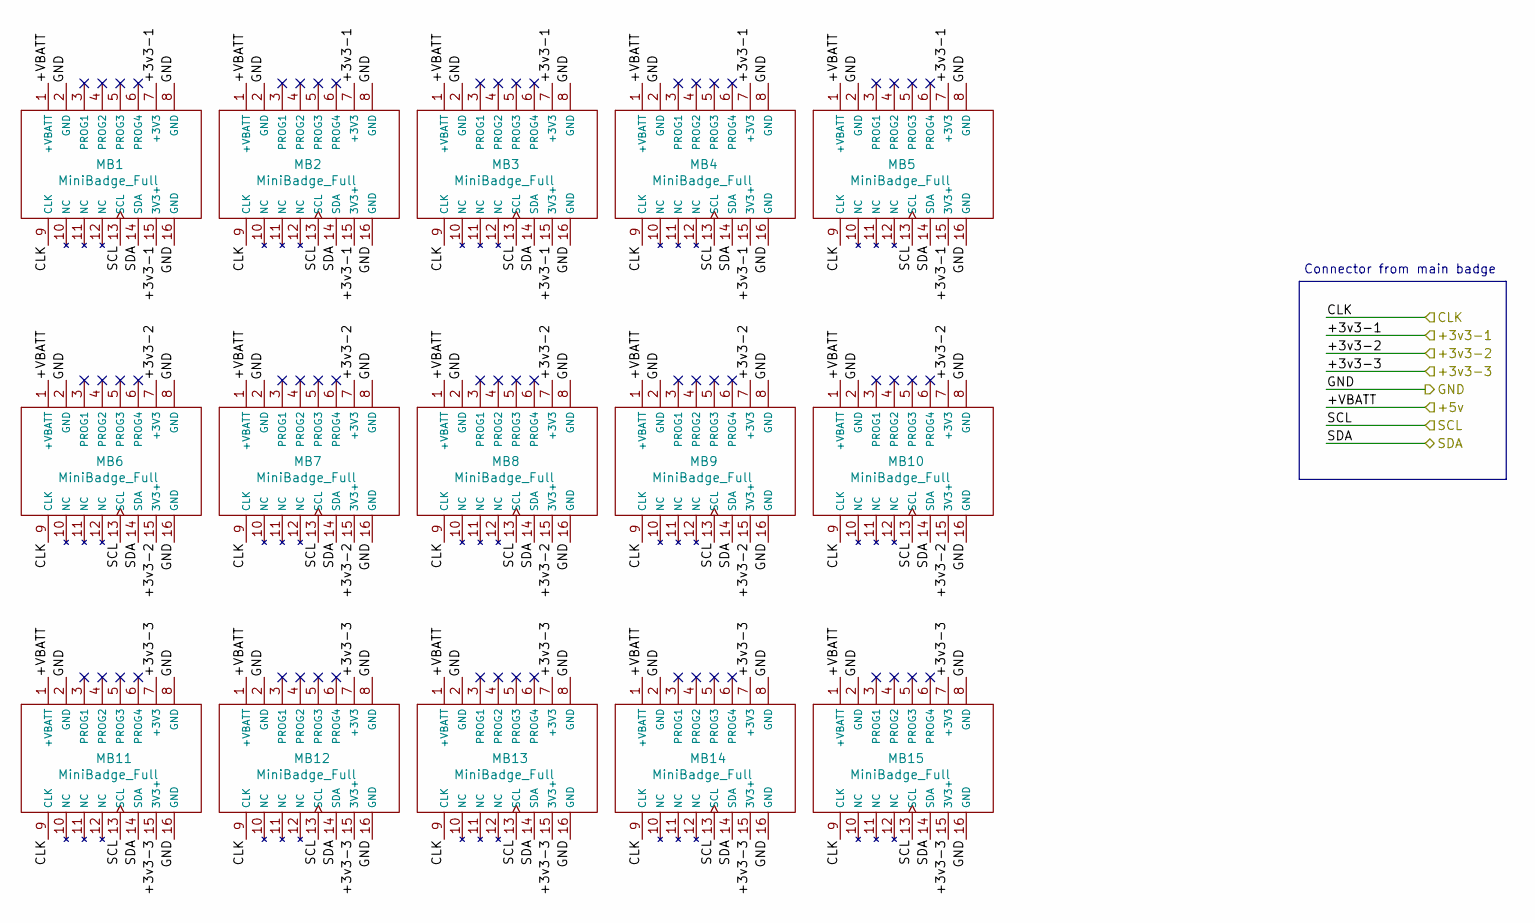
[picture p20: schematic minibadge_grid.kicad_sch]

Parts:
MB1, MB2, MB3, MB4, MB5, MB6, MB7, MB8, MB9, MB10, MB11, MB12, MB13, MB14, MB15: MiniBadge_Full; MiniBadge_Slot_Reflective

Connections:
+3v3-1: MB1.7 (+3V3), MB1.15 (3V3+), MB2.7 (+3V3), MB2.15 (3V3+), MB3.7 (+3V3), MB3.15 (3V3+), MB4.7 (+3V3), MB4.15 (3V3+), MB5.7 (+3V3), MB5.15 (3V3+); also elsewhere on the board
+3v3-2: MB6.7 (+3V3), MB6.15 (3V3+), MB7.7 (+3V3), MB7.15 (3V3+), MB8.7 (+3V3), MB8.15 (3V3+), MB9.7 (+3V3), MB9.15 (3V3+), MB10.7 (+3V3), MB10.15 (3V3+); also elsewhere on the board
+3v3-3: MB11.7 (+3V3), MB11.15 (3V3+), MB12.7 (+3V3), MB12.15 (3V3+), MB13.7 (+3V3), MB13.15 (3V3+), MB14.7 (+3V3), MB14.15 (3V3+), MB15.7 (+3V3), MB15.15 (3V3+); also elsewhere on the board
+5V: MB1.1 (+VBATT), MB2.1 (+VBATT), MB3.1 (+VBATT), MB4.1 (+VBATT), MB5.1 (+VBATT), MB6.1 (+VBATT), MB7.1 (+VBATT), MB8.1 (+VBATT), MB9.1 (+VBATT), MB10.1 (+VBATT), MB11.1 (+VBATT), MB12.1 (+VBATT), MB13.1 (+VBATT), MB14.1 (+VBATT), MB15.1 (+VBATT); also elsewhere on the board
GND: MB1.2 (GND), MB1.8 (GND), MB1.16 (GND), MB2.2 (GND), MB2.8 (GND), MB2.16 (GND), MB3.2 (GND), MB3.8 (GND), MB3.16 (GND), MB4.2 (GND), MB4.8 (GND), MB4.16 (GND), MB5.2 (GND), MB5.8 (GND), MB5.16 (GND), MB6.2 (GND), MB6.8 (GND), MB6.16 (GND), MB7.2 (GND), MB7.8 (GND), MB7.16 (GND), MB8.2 (GND), MB8.8 (GND), MB8.16 (GND), MB9.2 (GND), MB9.8 (GND), MB9.16 (GND), MB10.2 (GND), MB10.8 (GND), MB10.16 (GND), MB11.2 (GND), MB11.8 (GND), MB11.16 (GND), MB12.2 (GND), MB12.8 (GND), MB12.16 (GND), MB13.2 (GND), MB13.8 (GND), MB13.16 (GND), MB14.2 (GND), MB14.8 (GND), MB14.16 (GND), MB15.2 (GND), MB15.8 (GND), MB15.16 (GND); also elsewhere on the board
MB_CLK: MB1.9 (CLK), MB2.9 (CLK), MB3.9 (CLK), MB4.9 (CLK), MB5.9 (CLK), MB6.9 (CLK), MB7.9 (CLK), MB8.9 (CLK), MB9.9 (CLK), MB10.9 (CLK), MB11.9 (CLK), MB12.9 (CLK), MB13.9 (CLK), MB14.9 (CLK), MB15.9 (CLK); also elsewhere on the board
MB_SCL: MB1.13 (SCL), MB2.13 (SCL), MB3.13 (SCL), MB4.13 (SCL), MB5.13 (SCL), MB6.13 (SCL), MB7.13 (SCL), MB8.13 (SCL), MB9.13 (SCL), MB10.13 (SCL), MB11.13 (SCL), MB12.13 (SCL), MB13.13 (SCL), MB14.13 (SCL), MB15.13 (SCL); also elsewhere on the board
MB_SDA: MB1.14 (SDA), MB2.14 (SDA), MB3.14 (SDA), MB4.14 (SDA), MB5.14 (SDA), MB6.14 (SDA), MB7.14 (SDA), MB8.14 (SDA), MB9.14 (SDA), MB10.14 (SDA), MB11.14 (SDA), MB12.14 (SDA), MB13.14 (SDA), MB14.14 (SDA), MB15.14 (SDA); also elsewhere on the board

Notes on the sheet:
Connector from main badge

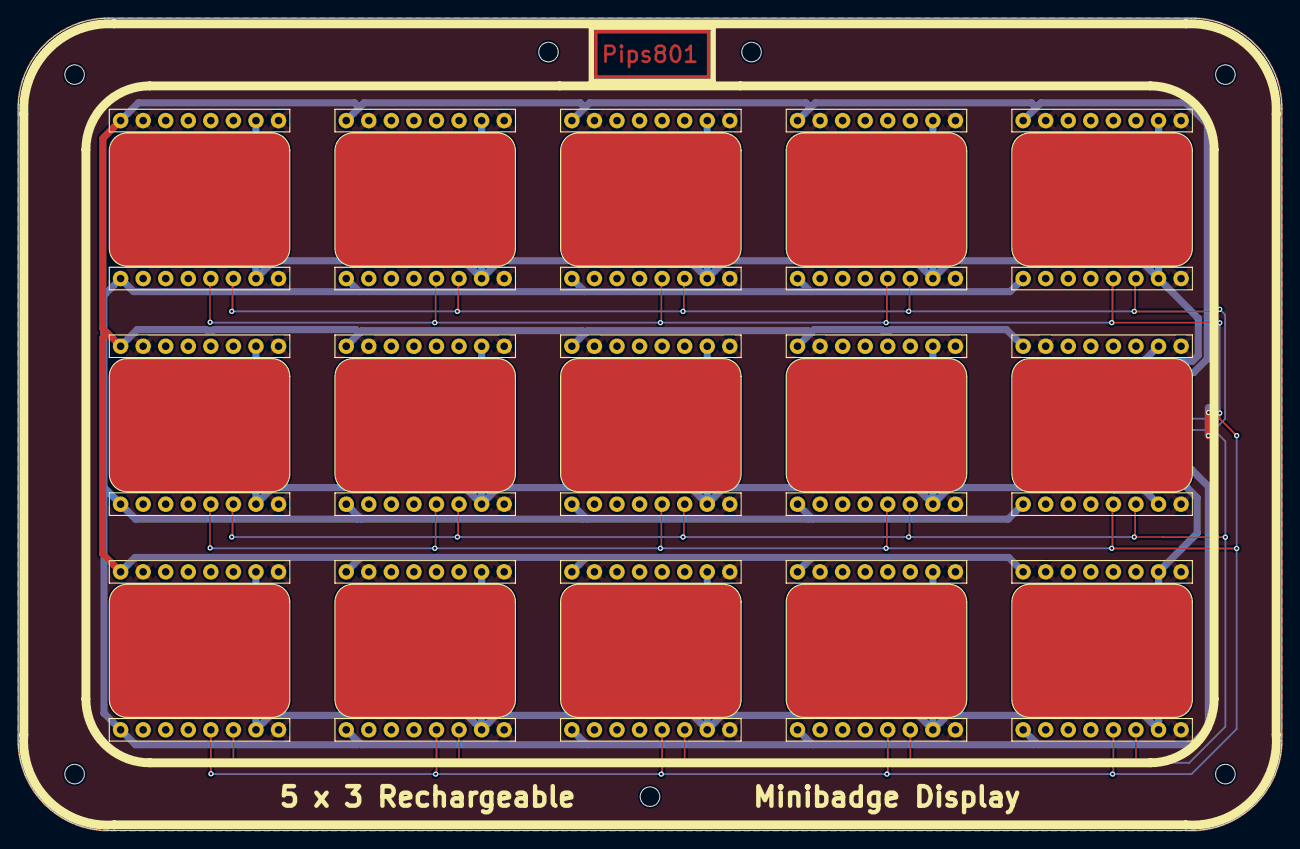
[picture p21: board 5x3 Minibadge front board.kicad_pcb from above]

Board: 2 copper layers, 142.2 x 91.4 mm, 16 parts (1 on the bottom side), 8 nets.

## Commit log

2025-01-15 flash + bms + usb switch
    [BMS.kicad_sch, Flash.kicad_sch, Minibadge Display 5x3 back plate.kicad_pcb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]
2025-01-15 BMS work
    [BMS.kicad_sch, Minibadge Display 5x3.kicad_sch, USB Switch.kicad_sch]
2025-01-15 rp2040 sub sheet
    [RP2040.kicad_sch]
2025-01-17 more rp2040 work
    -BMS updates
    - rp2040 updates
    - add hardware design docs
    [BMS.kicad_sch, Minibadge Display 5x3.kicad_pcb, Minibadge Display 5x3.kicad_sch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]
2025-01-20 BMS updates
    - BMS mostly done
    - all BMS pins connected to RP2040
    - Re-did Minibadge pinouts
    - Connected RP2040 to USB Switch
    [BMS.kicad_sch, Flash.kicad_sch, Minibadge Display 5x3.kicad_sch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]
2025-01-20 BMS updates
    Added missing capacitor for OTG
    [BMS.kicad_sch, Flash.kicad_sch, Minibadge Display 5x3.kicad_sch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]
2025-01-20 Move to sub-folders
    [5x3 Minibadge front board.kicad_pcb, 5x3 Minibadge front board.kicad_sch, BMS.kicad_sch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]
2025-01-20 Big changes
    - Folder changes
    - change dimensions of board to match thicker material
    - begin part selection/footprint selection
    [5x3 Minibadge front board.kicad_pcb, 5x3 Minibadge front board.kicad_sch, BMS.kicad_sch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]
2025-01-20 Schematic changes
    - changed positions/schematic values and nets
    [BMS.kicad_sch, Display main board.kicad_sch, Flash.kicad_sch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]
2025-01-20 FIxing issues
    - Messed up mounting holes
    - board didn't copy to front plate
    [5x3 Minibadge front board.kicad_pcb, Display main board.kicad_sch]
2025-01-21 Routed Minibadge Display
    god that sucked, and my routing sucks too.
    [5x3 Minibadge front board.kicad_pcb, 5x3 Minibadge front board.kicad_sch, RP2040.kicad_sch]
2025-01-21 small chages
    [5x3 Minibadge front board.kicad_sch, Display main board.kicad_pcb, minibadge_grid.kicad_sch]
2025-01-21 Fix DRC errors
    got it down from 20+ Errors and 200+ warnings to zero errors and some unnecessary warnings!
    [5x3 Minibadge front board.kicad_pcb]
2025-01-21 Add Voltage Regulators
    TLV1117LV33
    [Display main board.kicad_sch, Power.kicad_sch, RP2040.kicad_sch]
2025-01-22 hardware changes and initial traces/layout
    [5x3 Minibadge front board.kicad_pcb, BMS.kicad_sch, Display main board.kicad_pcb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]
2025-01-22 Add Crystal
    [BMS.kicad_sch, Flash.kicad_sch, RP2040.kicad_sch]
2025-01-22 1st semi complete board layout
    [Display main board.kicad_pcb, RP2040.kicad_sch]
2025-01-22 add JST connector
    [S3B-XH-SM4-TB_LF__SN_.stp]
2025-01-22 Finish routing
    [BMS.kicad_sch, Flash.kicad_sch, RP2040.kicad_sch]
2025-01-22 Forgot to route the TPM
    [Display main board.kicad_pcb]
2025-01-22 update power for TPM
    [Display main board.kicad_sch, Power.kicad_sch, RP2040.kicad_sch]
2025-01-23 Add resistor for ILIM pin
    [BMS.kicad_sch, Display main board.kicad_pcb]
2025-01-23 Diff Pair matching
    matched all USB lines to be within 1mm of length to each other
    [Display main board.kicad_pcb]
2025-01-23 more diff pair matching, fixed BMD Data lines
    [Display main board.kicad_pcb]
2025-01-23 add battery label
    [Display main board.kicad_pcb]
2025-01-23 Link USB-C port 3d model
    [Display main board.kicad_pcb]
2025-01-23 Change board size + mounting holes
    still need to finish re-routing the front plate
    [5x3 Minibadge front board.kicad_pcb, Display main board.kicad_pcb]
2025-01-23 physical changes
    [5x3 Minibadge front board.kicad_pcb, Display main board.kicad_pcb]
2025-01-23 re-routed front minibadge board
    [5x3 Minibadge front board.kicad_pcb]
2025-01-23 remove wrong files
    [TS3USB221A.step]
2025-01-23 front board initial silkscreen
    [5x3 Minibadge front board.kicad_pcb]
2025-01-23 Silkscreen updates
    [5x3 Minibadge front board.kicad_pcb]
2025-01-23 Part selection
    [BMS.kicad_sch, Display main board.kicad_pcb, Flash.kicad_sch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]
2025-01-23 Swap 260Ω footprint for 0805
    [BMS.kicad_sch, Display main board.kicad_pcb]
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2025-01-24 Fixed BMS_STAT pin
    [Display main board.kicad_sch, Flash.kicad_sch, RP2040.kicad_sch]
2025-01-24 Fix BMS_STAT pin
    swapped RP2040 footprint for one with thermal vias
    [Display main board.kicad_pcb, Display main board.kicad_sch, RP2040.kicad_sch]
2025-01-25 Fix typo
    [5x3 Minibadge front board.kicad_pcb]
2025-01-26 Reworking BMS
    [BMS.kicad_sch, Display main board.kicad_sch, Flash.kicad_sch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]
2025-01-27 refactor BMD schematic
    [BMS.kicad_sch]
2025-01-27 complete BMS layout
    [BMS.kicad_sch]
2025-01-27 Update GND symbols
    [Display main board.kicad_pcb, Display main board.kicad_sch, Power.kicad_sch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]
2025-01-28 refactor PCB for new BMS layout
    [BMS.kicad_sch, Display main board.kicad_pcb, Display main board.kicad_sch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]
2025-01-29 All components routed
    - broke out resistor network into individual resistors
    - AGND tied to PGND by BMS
    - repositioned GPIO positions
    - length-matched USB to within 0.1mm
    [BMS.kicad_sch, Display main board.kicad_pcb, Display main board.kicad_sch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]
2025-01-29 debug pins for RP2040
    [Display main board.kicad_pcb, RP2040.kicad_sch]
2025-01-29 Add TagConnect SWD
    [Display main board.kicad_pcb, RP2040.kicad_sch]
2025-01-29 add PawConnect
    [Display main board.kicad_pcb, RP2040.kicad_sch]
2025-01-29 minor route changes
    [Display main board.kicad_pcb]
2025-01-29 GND stitching/thermal relief for voltage regulators
    [Display main board.kicad_pcb]
2025-01-29 Via stitching
    [Display main board.kicad_pcb]
2025-01-29 Update JST to white
    [S3B-XH-SM4-TB_LF__SN_.stp]
2025-01-29 update 3d models
    [Display main board.kicad_pcb, IHLP2525CZ.step]
2025-01-29 swap PawConnect header
    [RP2040.kicad_sch]
2025-01-29 Swap PawConnect side
    [Display main board.kicad_pcb]
2025-01-29 Initial graphics update
    [Display main board.kicad_pcb]
2025-01-29 Add button and LEDs
    [BMS.kicad_sch, Display main board.kicad_pcb, Flash.kicad_sch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]
2025-01-30 Route 8x WS2812B-2020 LEDs
    [Display main board.kicad_pcb]
2025-01-30 move debug header
    [Display main board.kicad_pcb]
2025-01-30 Silkscreen sectioning
    [Display main board.kicad_pcb]
2025-01-30 remove unused traces
    [Display main board.kicad_pcb]
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2025-01-30 fix nets
    [Display main board.kicad_pcb, RP2040.kicad_sch]
2025-01-30 add caps for LEDs
    [Display main board.kicad_pcb, RP2040.kicad_sch]
2025-01-30 update 0.1uf caps to 0402
    [Display main board.kicad_pcb]
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2025-01-30 swap diode footprint + add new part numbers
    [BMS.kicad_sch, Display main board.kicad_pcb, Flash.kicad_sch]
2025-01-30 update ILIM resistor for 250ohm
    [BMS.kicad_sch, Display main board.kicad_pcb]
2025-01-30 Exclude BMS Reset from BOM
    [BMS.kicad_sch, Display main board.kicad_pcb]
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2025-01-30 fix ohm s ymbol
    [USB-C.kicad_sch]
2025-01-30 Update Display main board.kicad_pcb
    [Display main board.kicad_pcb]
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2025-01-30 add Wh capacity + swap pawprints
    [Display main board.kicad_pcb]
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
